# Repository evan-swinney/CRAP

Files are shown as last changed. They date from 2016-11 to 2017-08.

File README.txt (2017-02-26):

The Common Rocketry Avionics Package (CRAP) project is a rocket avionics package, designed specifically for UAH Space Hardware Club to be flown on the multistage team's rocket.  This payload will also serve as an in-house alternative to L1 Certifications and general rocketry for data collection and GPS tracking.  This payload will fire all rocket ordance and motors as well as provide data telemetry and storage.

. . . . . . . . . . . . . . . . . . . . . . . . . . . . . . . . . . . . . . . . . . . 

Designed by:
Cooper Barry - Team lead
Evan Swinney - Hardware design
James Biaglow - Hardware design and integration
Daniel Corey - Software Design
Will Watson - Software Design

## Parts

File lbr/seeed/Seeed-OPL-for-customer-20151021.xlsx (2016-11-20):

OPL list
Seeed SKU | MPN | Description | Category | Package | Manufacturer | Datasheet | Price（$）/pcs | Pieces/set | Solder points Qty | Assem.Cost/pcs（$） | Image URL | Distributor-URL
306010055 | FC-135 | SMD Crystal ABS07-32.768KHZ-7pF-20ppm-70K; | Crystal Oscillator | 2P-L3.2*W1.5mm | Xinhunjing | http://www.seeedstudio.com/wiki/images/7/78/306010055.pdf | 0.350 | 5 | 4 | 0.40 |  | http://www.seeedstudio.com/depot/OPLopen-parts-library-catalog-c-136_138/#306010055
306010005 | 49S | DIP Crystal 25MHz-20pF-20ppm;HC49US | Crystal Oscillator | HC49US | Xinhunjing | http://www.seeedstudio.com/wiki/images/5/5e/306010005.pdf | 0.150 | 10 | 2 | 0.20 |  | http://www.seeedstudio.com/depot/OPLopen-parts-library-catalog-c-136_138/#306010005
306010037 | 49S/18PF | DIP Crystal 16MHz-18pF-30ppm-50R; | Crystal Oscillator | HC49/US | Xinhunjing | http://www.seeedstudio.com/wiki/images/5/57/306010037.pdf | 0.150 | 10 | 2 | 0.20 |  | http://www.seeedstudio.com/depot/OPLopen-parts-library-catalog-c-136_138/#306010037
306010054 | X053201602002 | SMD 16MHz-8pF-20ppm-40R | Crystal Oscillator | 2P-SMD-5.0X3.2 | JINGPENGYUAN | http://www.seeedstudio.com/wiki/images/9/9f/0500290P1.pdf | 0.350 | 5 | 2 | 0.20 |  | http://www.seeedstudio.com/depot/OPLopen-parts-library-catalog-c-136_138/#0500290P1
306010047 | 5032/2P | SMD Crystal 12Mhz-20pF-20ppm-40R; | Crystal Oscillator | 2P-L5.0*W3.2mm | Xinhunjing | http://www.seeedstudio.com/wiki/images/c/c7/306010047.pdf | 0.450 | 5 | 2 | 0.20 |  | http://www.seeedstudio.com/depot/OPLopen-parts-library-catalog-c-136_138/#306010047
306010004 | 5032/4P | SMD Crystal 8MHz-20pF-20ppm; | Crystal Oscillator | 2P-L5.0*W3.2mm | Xinhunjing | http://www.seeedstudio.com/wiki/images/9/91/306010004.pdf | 0.450 | 5 | 2 | 0.20 |  | http://www.seeedstudio.com/depot/OPLopen-parts-library-catalog-c-136_138/#306010004
306010033 | 49S8M | DIP Crystal 8MHz-20pF-20ppm-60R; | Crystal Oscillator | HC49S | Xinhunjing | http://www.seeedstudio.com/wiki/images/c/ca/306010033.pdf | 0.150 | 10 | 2 | 0.20 |  | http://www.seeedstudio.com/depot/OPLopen-parts-library-catalog-c-136_138/#306010033
305030028 | 2N7002,215 | SMD MOSFET N-CH 60V-300mA Logic Level FET; | Transistor | SOT-23 | NXP | http://www.seeedstudio.com/wiki/images/c/c6/305030028.pdf | 0.050 | 30 | 3 | 0.30 |  | http://www.seeedstudio.com/depot/OPLopen-parts-library-catalog-c-136_138/#305030028
305030015 | CJ2302 | SMD MOSFET N-CH 20V 2.1A | Transistor | SOT23 | JCET | http://www.seeedstudio.com/wiki/images/e/e7/0440200P1.pdf | 0.100 | 10 | 3 | 0.30 |  | http://www.seeedstudio.com/depot/OPLopen-parts-library-catalog-c-136_138/#0440200P1
305030018 | Si2343CDS | SMD MOSFET P-CH 30V-5.9A | Transistor | SOT-23 | Vishay Siliconix |  | 0.700 | 5 | 3 | 0.30 |  | http://www.seeedstudio.com/depot/OPLopen-parts-library-catalog-c-136_138/#305030018
305030014 | CJ2305 | SMD MOSFET P-CH -8V -4.1A | Transistor | SOT-23 | JCET | http://www.seeedstudio.com/wiki/images/a/ac/0440210P1.pdf | 0.100 | 10 | 3 | 0.30 |  | http://www.seeedstudio.com/depot/OPLopen-parts-library-catalog-c-136_138/#0440210P1
305010018 | S9013 | SMD Transistors NPN 25V-500mA | Transistor | SOT-23 | JCET | http://www.seeedstudio.com/wiki/images/6/67/0400000P1.pdf | 0.040 | 50 | 3 | 0.30 |  | http://www.seeedstudio.com/depot/OPLopen-parts-library-catalog-c-136_138/#0400000P1
305020006 | S8550 | SMD Transistors PNP 25V-500mA | Transistor | SOT-23 |  | http://www.seeedstudio.com/wiki/images/e/e5/0410030P1.pdf | 0.040 | 50 | 3 | 0.30 |  | http://www.seeedstudio.com/depot/OPLopen-parts-library-catalog-c-136_138/#0410030P1
305010017 | S8050 | SMD Transistors NPN 25V-500mW; | Transistor | SOT-23 | JCET | http://www.seeedstudio.com/wiki/images/b/ba/305010017.pdf | 0.040 | 50 | 3 | 0.30 |  | http://www.seeedstudio.com/depot/OPLopen-parts-library-catalog-c-136_138/#305010017
305010022 | S9014J6 | SMD Transistor NPN 50V-100mA; | Transistor | SOT-23 | Changjiang | http://www.seeedstudio.com/wiki/images/2/2c/305010022.pdf | 0.050 | 30 | 3 | 0.30 |  | http://www.seeedstudio.com/depot/OPLopen-parts-library-catalog-c-136_138/#305010022
312010004 | KS-12065D03YA | DIP Buzzer 3V,30mA, 2700±300Hz | Audio product | 2P-7.6-D12*H6.5mm | Guangjixing | http://www.seeedstudio.com/wiki/images/c/cb/312020003.pdf | 0.500 | 5 | 2 | 0.20 |  | http://www.seeedstudio.com/depot/OPLopen-parts-library-catalog-c-136_138/#312010004
302020027 | TAJD477M006RNJ | SMD CAP Tantalum 470uF-6.3V;D | Capacitor | AVX-D | AVX |  | 0.500 | 5 | 2 | 0.20 |  | http://www.seeedstudio.com/depot/OPLopen-parts-library-catalog-c-136_138/#302020027
302030031 |  | DIP CAP Aluminum 100uF-16V | Capacitor | Radial-D5.0*H7.0mm | JWCO | http://www.seeedstudio.com/wiki/images/1/14/302030031.pdf | 0.030 | 50 | 2 | 0.20 |  | http://www.seeedstudio.com/depot/OPLopen-parts-library-catalog-c-136_138/#302030031
302020025 | TAJC107K010RNJ | SMD CAP Tantalum 100uF-10V 10% | Capacitor | AVX-C | AVX | http://www.seeedstudio.com/wiki/images/a/ae/0130170P1.pdf | 0.200 | 10 | 2 | 0.20 |  | http://www.seeedstudio.com/depot/OPLopen-parts-library-catalog-c-136_138/#0130170P1
302020022 | TAJC476K016RNJ | SMD CAP Tantalum 47uF-16V | Capacitor | AVX-C | AVX | http://www.seeedstudio.com/wiki/images/c/c7/302020022.pdf | 0.200 | 10 | 2 | 0.20 |  | http://www.seeedstudio.com/depot/OPLopen-parts-library-catalog-c-136_138/#302020022
302020020 | TAJB476K010RNJ | SMD CAP Tantalum 47uF-10V 10% | Capacitor | AVX-B | AVX | http://www.seeedstudio.com/wiki/images/f/fb/0130180P1.pdf | 0.200 | 10 | 2 | 0.20 |  | http://www.seeedstudio.com/depot/OPLopen-parts-library-catalog-c-136_138/#0130180P1
302020005 | TAJC476K006RNJ | SMD CAP Tantalum 47uF-6.3V | Capacitor | AVX-A | AVX |  | 0.150 | 20 | 2 | 0.20 |  | http://www.seeedstudio.com/depot/OPLopen-parts-library-catalog-c-136_138/#302020005
302020026 | TAJC226K025RNJ | SMD CAP Tantalum 22uF-25V 10% 2312 | Capacitor | AVX-C | AVX | http://www.seeedstudio.com/wiki/images/f/fd/0130360P1.pdf | 0.370 | 10 | 2 | 0.20 |  | http://www.seeedstudio.com/depot/OPLopen-parts-library-catalog-c-136_138/#0130360P1
302020021 | TAJB226K010RNJ | SMD CAP Tantalum 22uF-10V 10% | Capacitor | AVX-B | AVX | http://www.seeedstudio.com/wiki/images/8/82/0130240P1.pdf | 0.130 | 20 | 2 | 0.20 |  | http://www.seeedstudio.com/depot/OPLopen-parts-library-catalog-c-136_138/#0130240P1
302010171 | CC0805MKX5R5BB226 | SMD CAP Ceramic 22uF-6.3V-20%-X5R; | Capacitor | 0805 | YAGEO |  | 0.050 | 50 | 2 | 0.20 |  | http://www.seeedstudio.com/depot/OPLopen-parts-library-catalog-c-136_138/#302010171
302010181 | CC1206KKX5R8BB106 | SMD CAP Ceramic 10uF-25V-10%-X5R | Capacitor | 1206 | YAGEO |  | 0.130 | 20 | 2 | 0.20 |  | http://www.seeedstudio.com/depot/OPLopen-parts-library-catalog-c-136_138/#302010181
302010178 | CC0805KKX5R8BB106 | SMD CAP Ceramic 10uF-25V-10%-X5R | Capacitor | 0805 | YAGEO | http://www.seeedstudio.com/wiki/images/2/20/0100080P1.pdf | 0.050 | 50 | 2 | 0.20 |  | http://www.seeedstudio.com/depot/OPLopen-parts-library-catalog-c-136_138/#0100080P1
302020019 | TAJB106K016RNJ | SMD CAP Tantalum 10uF-16V 10% | Capacitor | AVX-B | AVX | http://www.seeedstudio.com/wiki/images/f/f6/0130120P1.pdf | 0.150 | 20 | 2 | 0.20 |  | http://www.seeedstudio.com/depot/OPLopen-parts-library-catalog-c-136_138/#0130120P1
302020002 | TAJA106K016RNJ | SMD CAP Tantalum 10uF-16V 10% | Capacitor | AVX-A | AVX | http://www.seeedstudio.com/wiki/images/1/1b/0130050P1.pdf | 0.130 | 20 | 2 | 0.20 |  | http://www.seeedstudio.com/depot/OPLopen-parts-library-catalog-c-136_138/#0130050P1
302020011 | TAJA106K010RNJ | SMD CAP Tantalum 10uF-10V 10% | Capacitor | AVX-A | AVX | http://www.seeedstudio.com/wiki/images/5/59/0130040P1.pdf (http://www.seeedstudio.com/wiki/images/0/0d/302010146.pdf) | 0.130 | 20 | 2 | 0.20 |  | http://www.seeedstudio.com/depot/OPLopen-parts-library-catalog-c-136_138/#0130040P1
302010243 | CC1206KKX5R9BB475 | SMD CAP Ceramic 4.7uF-50V-10%-X5R; | Capacitor | 1206 | YAGEO |  | 0.250 | 10 | 2 | 0.20 |  | http://www.seeedstudio.com/depot/OPLopen-parts-library-catalog-c-136_138/#302010243
302010146 | CC0805KKX5R8BB475 | SMD CAP Ceramic 4.7uF-25V-10%-X5R;0805 | Capacitor | C0805 | YAGEO | http://www.seeedstudio.com/wiki/images/0/0d/302010146.pdf | 0.040 | 50 | 2 | 0.20 |  | http://www.seeedstudio.com/depot/OPLopen-parts-library-catalog-c-136_138/#302010146
302010111 | CC0603KRX5R6BB475 | SMD CAP Ceramic 4.7uF-10V-10%-X5R; | Capacitor | 0603 | YAGEO |  | 0.040 | 50 | 2 | 0.20 |  | http://www.seeedstudio.com/depot/OPLopen-parts-library-catalog-c-136_138/#302010111
302010019 | CC0402MRX5R5BB475 | SMD CAP Ceramic 4.7uF-6.3V-20%-X5R | Capacitor | 0402 | YAGEO |  | 0.200 | 10 | 2 | 0.20 |  | http://www.seeedstudio.com/depot/OPLopen-parts-library-catalog-c-136_138/#302010019
302010148 | CC0805KKX7R8BB225 | SMD CAP Ceramic 2.2uF-25V-10%-X7R;0805 | Capacitor | C0805 | YAGEO | http://www.seeedstudio.com/wiki/images/a/ac/302010056.pdf | 0.050 | 50 | 2 | 0.20 |  | http://www.seeedstudio.com/depot/OPLopen-parts-library-catalog-c-136_138/#302010148
302010179 | CC0805KKX7R8BB105 | SMD CAP Ceramic 1uF-25V-10%-X7R | Capacitor | 0805 | YAGEO | http://www.seeedstudio.com/wiki/images/8/89/0100440P1.pdf (http://www.seeedstudio.com/wiki/images/a/ac/302010056.pdf) | 0.030 | 50 | 2 | 0.20 |  | http://www.seeedstudio.com/depot/OPLopen-parts-library-catalog-c-136_138/#0100440P1
302010139 | CC0603KRX7R8BB105 | SMD CAP Ceramic 1uF-25V-10%-X7R | Capacitor | 0603 | YAGEO | http://www.seeedstudio.com/wiki/images/a/af/0100340P1.pdf (http://www.seeedstudio.com/wiki/File:302010056.pdf) | 0.015 | 100 | 2 | 0.20 |  | http://www.seeedstudio.com/depot/OPLopen-parts-library-catalog-c-136_138/#0100340P1
302010040 | CC0402KRX5R6BB105 | SMD CAP Ceramic 1uF-10V-10%-X5R | Capacitor | 0402 | YAGEO |  | 0.015 | 100 | 2 | 0.20 |  | http://www.seeedstudio.com/depot/OPLopen-parts-library-catalog-c-136_138/#302010040
302010073 | CC0603KRX7R8BB224 | SMD CAP Ceramic 220nF-25V-10%-X7R;0603 | Capacitor | 0603 | YAGEO | http://www.seeedstudio.com/wiki/images/a/ac/302010056.pdf | 0.015 | 100 | 2 | 0.20 |  | http://www.seeedstudio.com/depot/OPLopen-parts-library-catalog-c-136_138/#302010073
302010165 | CC0805KRX7R9BB104 | SMD CAP Ceramic 100nF-50V-10%-X7R; | Capacitor | 0805 | YAGEO | http://www.seeedstudio.com/wiki/File:302010056.pdf (http://www.seeedstudio.com/wiki/images/a/ac/302010056.pdf) | 0.015 | 100 | 2 | 0.20 |  | http://www.seeedstudio.com/depot/OPLopen-parts-library-catalog-c-136_138/#302010165
302010138 | CC0603KRX7R9BB104 | SMD CAP Ceramic 100nF-50V-10%-X7R | Capacitor | 0603 | YAGEO | http://www.seeedstudio.com/wiki/images/3/35/0100020P1.pdf | 0.015 | 100 | 2 | 0.20 |  | http://www.seeedstudio.com/depot/OPLopen-parts-library-catalog-c-136_138/#0100020P1
302010024 | CC0402KRX7R8BB104 | SMD CAP Ceramic 100nF-25V-10%-X7R | Capacitor | 0402 | YAGEO | http://www.seeedstudio.com/wiki/images/a/ac/302010056.pdf | 0.015 | 100 | 2 | 0.20 |  | http://www.seeedstudio.com/depot/OPLopen-parts-library-catalog-c-136_138/#302010024
302010002 | CC0402KRX7R8BB473 | SMD CAP Ceramic 47nF-25V-10%-X7R; | Capacitor | 0402 | YAGEO |  | 0.010 | 100 | 2 | 0.20 |  | http://www.seeedstudio.com/depot/OPLopen-parts-library-catalog-c-136_138/#302010002
302010088 | CC0603KRX7R9BB333 | SMD CAP Ceramic 33nF-50V-10%-X7R;0603 | Capacitor | 0603 | YAGEO | http://www.seeedstudio.com/wiki/images/a/ac/302010056.pdf | 0.015 | 100 | 2 | 0.20 |  | http://www.seeedstudio.com/depot/OPLopen-parts-library-catalog-c-136_138/#302010088
302010095 | CC0603KRX7R9BB223 | SMD CAP Ceramic 22nF-50V-10%-X7R;0603 | Capacitor | C0603 | YAGEO | http://www.seeedstudio.com/wiki/images/a/ac/302010056.pdf | 0.010 | 100 | 2 | 0.20 |  | http://www.seeedstudio.com/depot/OPLopen-parts-library-catalog-c-136_138/#302010095
302010202 |  | DIP CAP Ceramic Disc 10nF-50V-Y5V | Capacitor | Radial-Disc-2.5-D4.0mm |  |  | 0.015 | 100 | 2 | 0.20 |  | http://www.seeedstudio.com/depot/OPLopen-parts-library-catalog-c-136_138/#302010202
302010140 | CC0603KRX7R9BB103 | SMD CAP Ceramic 10nF-50V-10%-X7R | Capacitor | 0603 | YAGEO | http://www.seeedstudio.com/wiki/images/e/eb/0100350P1.pdf (http://www.seeedstudio.com/wiki/images/f/f0/302010067.pdf%20302010094) | 0.010 | 100 | 2 | 0.20 |  | http://www.seeedstudio.com/depot/OPLopen-parts-library-catalog-c-136_138/#0100350P1
302010006 | CC0402KRX7R9BB103 | SMD CAP Ceramic 10nF-50V-10%-X7R | Capacitor | 0402 | YAGEO | http://www.seeedstudio.com/wiki/images/f/f0/302010067.pdf | 0.010 | 100 | 2 | 0.20 |  | http://www.seeedstudio.com/depot/OPLopen-parts-library-catalog-c-136_138/#302010006
302010144 | CC0603KRX7R9BB472 | SMD CAP Ceramic 4.7nF-50V-10%-X7R | Capacitor | 0603 | YAGEO | http://www.seeedstudio.com/wiki/images/f/fd/0130360P1.pdf | 0.010 | 100 | 2 | 0.20 |  | http://www.seeedstudio.com/depot/OPLopen-parts-library-catalog-c-136_138/#0100850P1
302010056 | CC0603KRX7R9BB222 | SMD CAP Ceramic 2.2nF-50V-10%-X7R | Capacitor | 0603 | YAGEO | http://www.seeedstudio.com/wiki/images/a/ac/302010056.pdf | 0.010 | 100 | 2 | 0.20 |  | http://www.seeedstudio.com/depot/OPLopen-parts-library-catalog-c-136_138/#302010056
302010141 | CC0603KRX7R9BB102 | SMD CAP Ceramic 1nF-50V-10%-X7R | Capacitor | 0603 | YAGEO | http://www.seeedstudio.com/wiki/images/c/cf/0100370P1.pdf | 0.010 | 100 | 2 | 0.20 |  | http://www.seeedstudio.com/depot/OPLopen-parts-library-catalog-c-136_138/#0100370P1
302010005 | CC0402KRX7R9BB102 | SMD CAP Ceramic 1nF-50V-10%-X7R; | Capacitor | 0402 | YAGEO |  | 0.050 | 50 | 2 | 0.20 |  | http://www.seeedstudio.com/depot/OPLopen-parts-library-catalog-c-136_138/#302010005
302010094 | CC0603JRNPO9BN221 | SMD CAP Ceramic 220pF-50V-5%-NPO; | Capacitor | C0603 | YAGEO | http://www.seeedstudio.com/wiki/images/f/f0/302010067.pdf 302010094 (http://www.seeedstudio.com/wiki/File:302010067.pdf) | 0.020 | 100 | 2 | 0.20 |  | http://www.seeedstudio.com/depot/OPLopen-parts-library-catalog-c-136_138/#302010094
302010013 | CC0402JRNPO9BN221 | SMD CAP Ceramic 220pF-50V-5%-NPO | Capacitor | 0402 | YAGEO | http://www.seeedstudio.com/wiki/images/f/f0/302010067.pdf | 0.030 | 50 | 2 | 0.20 |  | http://www.seeedstudio.com/depot/OPLopen-parts-library-catalog-c-136_138/#302010013
302010076 | CC0603JRNPO9BN101 | SMD CAP Ceramic 100pF-50V-5%-NPO;0603 | Capacitor | 0603 | YAGEO | http://www.seeedstudio.com/wiki/images/f/f0/302010067.pdf | 0.010 | 100 | 2 | 0.20 |  | http://www.seeedstudio.com/depot/OPLopen-parts-library-catalog-c-136_138/#302010076
302010126 | CC0603JRNPO9BN390 | SMD CAP Ceramic 39pF-50V-5%-NPO;0603 | Capacitor | C0603 | YAGEO | http://www.seeedstudio.com/wiki/images/f/f0/302010067.pdf (http://www.seeedstudio.com/wiki/images/0/03/0100230P1.pdf) | 0.010 | 100 | 2 | 0.20 |  | http://www.seeedstudio.com/depot/OPLopen-parts-library-catalog-c-136_138/#302010126
302010150 | CC0805JRNPO9BN270 | SMD CAP Ceramic 27pF-50V-5%-NPO | Capacitor | 0805 | YAGEO | http://www.seeedstudio.com/wiki/images/b/be/320020004.png | 0.030 | 50 | 2 | 0.20 |  | http://www.seeedstudio.com/depot/OPLopen-parts-library-catalog-c-136_138/#302010150
302010142 | CC0603JRNPO9BN270 | SMD CAP Ceramic 27pF-50V-5%-NPO | Capacitor | 0603 | YAGEO | http://www.seeedstudio.com/wiki/images/0/01/0100410P1.pdf (http://www.seeedstudio.com/wiki/images/b/be/320020004.png) | 0.010 | 100 | 2 | 0.20 |  | http://www.seeedstudio.com/depot/OPLopen-parts-library-catalog-c-136_138/#0100410P1
302010027 | CC0402JRNPO9BN270 | SMD CAP Ceramic 27pF-50V-5%-NPO | Capacitor | 0402 | YAGEO | http://www.seeedstudio.com/wiki/images/b/be/320020004.png | 0.010 | 100 | 2 | 0.20 |  | http://www.seeedstudio.com/depot/OPLopen-parts-library-catalog-c-136_138/#302010027
302010143 | CC0603JRNPO9BN220 | SMD CAP Ceramic 22pF-50V-5%-NPO | Capacitor | 0603 | YAGEO | http://www.seeedstudio.com/wiki/images/7/73/0100620P1.pdf | 0.010 | 100 | 2 | 0.20 |  | http://www.seeedstudio.com/depot/OPLopen-parts-library-catalog-c-136_138/#0100620P1
302010018 | CC0402JRNPO9BN220 | SMD CAP Ceramic 22pF-50V-5%-NPO | Capacitor | 0402 | YAGEO | http://www.seeedstudio.com/wiki/File:302010067.pdf (http://www.seeedstudio.com/wiki/images/b/be/320020004.png) | 0.010 | 100 | 2 | 0.20 |  | http://www.seeedstudio.com/depot/OPLopen-parts-library-catalog-c-136_138/#302010018
302010162 | CC0805JRNPO9BN180 | SMD CAP Ceramic 18pF-50V-5%-NPO | Capacitor | 0805 | YAGEO |  | 0.010 | 100 | 2 | 0.20 |  | http://www.seeedstudio.com/depot/OPLopen-parts-library-catalog-c-136_138/#302010162
302010016 | CC0402JRNPO9BN180 | SMD CAP Ceramic 18pF-50V-5%-NPO | Capacitor | 0402 | YAGEO |  | 0.010 | 100 | 2 | 0.20 |  | http://www.seeedstudio.com/depot/OPLopen-parts-library-catalog-c-136_138/#302010016
302010083 | CC0603JRNPO9BN180 | SMD CAP Ceramic 18pF-50V-5%-NPO; | Capacitor | 0603 | YAGEO | http://www.seeedstudio.com/wiki/images/7/77/320020027.png | 0.010 | 100 | 2 | 0.20 |  | http://www.seeedstudio.com/depot/OPLopen-parts-library-catalog-c-136_138/#302010083
302010082 | CC0603JRNPO9BN150 | SMD CAP Ceramic 15pF-50V-5%-NPO;0603 | Capacitor | 0603 | YAGEO | http://www.seeedstudio.com/wiki/images/f/f0/302010067.pdf (http://www.seeedstudio.com/wiki/images/e/ef/320020003.png) | 0.010 | 100 | 2 | 0.20 |  | http://www.seeedstudio.com/depot/OPLopen-parts-library-catalog-c-136_138/#302010082
302010067 | CC0603JRNPO9BN120 | SMD CAP Ceramic 12pF-50V-5%-NP0 | Capacitor | 0603 | YAGEO | http://www.seeedstudio.com/wiki/images/f/f0/302010067.pdf | 0.010 | 100 | 2 | 0.20 |  | http://www.seeedstudio.com/depot/OPLopen-parts-library-catalog-c-136_138/#302010067
302010097 | CC0603JRNPO9BN100 | SMD CAP Ceramic 10pF-50V-5%-NPO | Capacitor | 0603 | YAGEO | http://www.seeedstudio.com/wiki/images/b/be/320020004.png | 0.010 | 100 | 2 | 0.20 |  | http://www.seeedstudio.com/depot/OPLopen-parts-library-catalog-c-136_138/#302010097
302010001 | CC0402JRNPO9BN100 | SMD CAP Ceramic 10pF-50V-5%-NPO | Capacitor | 0402 | YAGEO |  | 0.010 | 100 | 2 | 0.20 |  | http://www.seeedstudio.com/depot/OPLopen-parts-library-catalog-c-136_138/#302010001
302010223 | CC0402CRNPO9BN2R2 | SMD CAP Ceramic 2.2pF-50V-0.25PF-NPO | Capacitor | 0402 | YAGEO | http://www.seeedstudio.com/wiki/images/b/be/320020004.png | 0.010 | 100 | 2 | 0.20 |  | http://www.seeedstudio.com/depot/OPLopen-parts-library-catalog-c-136_138/#302010223
302010102 | CC0603CRNPO9BN2R2 | SMD CAP Ceramic 2.2pF-50V-0.25pF-NPO | Capacitor | 0603 | YAGEO |  | 0.010 | 100 | 2 | 0.20 |  | http://www.seeedstudio.com/depot/OPLopen-parts-library-catalog-c-136_138/#302010102
302010046 | GRM1555C1H1R8BA01D | SMD CAP Ceramic 1.8pF-50V-0.1pF-NPO | Capacitor | 0402 | Murata |  | 0.010 | 100 | 2 | 0.20 |  | http://www.seeedstudio.com/depot/OPLopen-parts-library-catalog-c-136_138/#302010046
320020037 | P125-1102A0BS116A3 | DIP White Male Header VERT; | Connector | 1*2P-2.54-2.54-11.6/3.0mm | YXCON | http://www.seeedstudio.com/wiki/images/b/be/320020004.png (http://www.seeedstudio.com/wiki/images/c/cb/320020019.png) | 0.100 | 20 | 2 | 0.20 |  | http://www.seeedstudio.com/depot/OPLopen-parts-library-catalog-c-136_138/#320020037
320020015 | P125-1102A0BS116A2 | DIP Blue Male Header VERT | Connector | 1*2P-2.54-2.54-11.6/3.0mm | YXCON | http://www.seeedstudio.com/wiki/images/b/be/320020004.png | 0.100 | 20 | 2 | 0.20 |  | http://www.seeedstudio.com/depot/OPLopen-parts-library-catalog-c-136_138/#320020015
320020016 | P125-1102A0BS116A1 | DIP Black Male Header VERT | Connector | 1*2P-2.54-2.54-11.6/3.0mm | YXCON | http://www.seeedstudio.com/wiki/images/b/be/320020004.png | 0.100 | 20 | 2 | 0.20 |  | http://www.seeedstudio.com/depot/OPLopen-parts-library-catalog-c-136_138/#320020016
320020079 |  | DIP-Black-Male-Header-VERT-3P | Connector | 1X3P-2.54-2.54-11.6/3.0 | YXCON | http://www.seeedstudio.com/wiki/images/0/02/3460810P1.pdf (http://www.seeedstudio.com/wiki/images/b/be/320020004.png) | 0.100 | 20 | 3 | 0.30 |  | http://www.seeedstudio.com/depot/OPLopen-parts-library-catalog-c-136_138/#3460810P1
320020038 | P125-1103A0BS116A1 | DIP White Male Header VERT; | Connector | 1*3P-2.54-2.54-11.6/3.0mm | YXCON | http://www.seeedstudio.com/wiki/images/b/be/320020004.png | 0.120 | 20 | 3 | 0.30 |  | http://www.seeedstudio.com/depot/OPLopen-parts-library-catalog-c-136_138/#320020038
320020061 | P125-1103A0BR138A1 | DIP Black Male Header R/A; | Connector | 1*3P-2.54-2.54-6.0mm-90D-1 | YXCON |  | 0.120 | 20 | 3 | 0.30 |  | http://www.seeedstudio.com/depot/OPLopen-parts-library-catalog-c-136_138/#320020061
320020077 | P125-12A1BS116A1 | DIP Black Male Header | Connector | 2X3P-2.54-2.54-11.6/3.0 | YXCON | http://www.seeedstudio.com/wiki/images/7/72/3460180P1.pdf (http://www.seeedstudio.com/wiki/images/8/8b/320020018.png) | 0.060 | 20 | 6 | 0.60 |  | http://www.seeedstudio.com/depot/OPLopen-parts-library-catalog-c-136_138/#3460180P1
320020027 | P125-1203A0BS116A2 | DIP Yellow Male Header VERT; | Connector | 2*3P-2.54-2.54-11.6/3.0mm | YXCON | http://www.seeedstudio.com/wiki/images/7/77/320020027.png | 0.100 | 20 | 6 | 0.60 |  | http://www.seeedstudio.com/depot/OPLopen-parts-library-catalog-c-136_138/#320020027
320020003 | P125-1203A0BS116A1 | DIP Blue Male Header VERT; | Connector | 2*3P-2.54-2.54-11.6/3.0mm | YXCON | http://www.seeedstudio.com/wiki/images/e/ef/320020003.png (http://www.seeedstudio.com/wiki/images/2/25/320020010.pdf) | 0.150 | 20 | 6 | 0.60 |  | http://www.seeedstudio.com/depot/OPLopen-parts-library-catalog-c-136_138/#320020003
320020017 | P125-1104A0BS116A1 | DIP Black Male Header VERT | Connector | 1*4P-2.54-2.54-11.6/3.0mm | YXCON | http://www.seeedstudio.com/wiki/images/f/fb/320020089.png | 0.100 | 20 | 4 | 0.40 |  | http://www.seeedstudio.com/depot/OPLopen-parts-library-catalog-c-136_138/#320020017
320020005 | P125-1106A0BS116A1 | DIP Blue Male Header VERT | Connector | 1*6P-2.54-2.54-11.6/3.0mm | YXCON | http://www.seeedstudio.com/wiki/images/b/be/320020004.png | 0.100 | 20 | 6 | 0.60 |  | http://www.seeedstudio.com/depot/OPLopen-parts-library-catalog-c-136_138/#320020005
320020078 | P125-1106A1BS116A1 | DIP Black Male Header | Connector | 1X6P-2.54-2.54-11.6/3.0mm | YXCON | http://www.seeedstudio.com/wiki/images/2/2d/3460650P1.pdf | 0.100 | 20 | 6 | 0.60 |  | http://www.seeedstudio.com/depot/OPLopen-parts-library-catalog-c-136_138/#3460650P1
320020022 | P125-1106A0BS116A2 | DIP White Male Header VERT; | Connector | 1*6P-2.54-2.54-11.6/3.0mm | YXCON | http://www.seeedstudio.com/wiki/images/b/be/320020004.png (http://www.seeedstudio.com/wiki/images/0/0d/320030039.pdf) | 0.100 | 20 | 6 | 0.60 |  | http://www.seeedstudio.com/depot/OPLopen-parts-library-catalog-c-136_138/#320020022
320020024 | P125-1106B0BA2 | SMD Blue Male Header R/A; | Connector | 1*6P-2.54-2.54-9.3/6.0mm-2 | YXCON | http://www.seeedstudio.com/wiki/images/e/ef/320120007.pdf | 0.100 | 20 | 6 | 0.60 |  | http://www.seeedstudio.com/depot/OPLopen-parts-library-catalog-c-136_138/#320020024
320020031 | P125-1106B0BA1 | SMD Black Male Header R/A; | Connector | 1*6P-2.54-2.54-9.3/6.0mm-2 | YXCON | http://www.seeedstudio.com/wiki/images/d/d3/320030100.png | 0.100 | 20 | 6 | 0.60 |  | http://www.seeedstudio.com/depot/OPLopen-parts-library-catalog-c-136_138/#320020031
320020019 | P125-1106A0BR138A1 | DIP Black Short Male Header R/A; | Connector | 1X6P-2.54-2.54-6.0mm-90D-1 | YXCON | http://www.seeedstudio.com/wiki/images/c/cb/320020019.png (http://www.seeedstudio.com/wiki/images/a/a7/320030035.png) | 0.100 | 20 | 6 | 0.60 |  | http://www.seeedstudio.com/depot/OPLopen-parts-library-catalog-c-136_138/#320020019
320020070 | P125-1106A0BR138A2 | DIP Black Male Header R/A; | Connector | 1*6P-2.54-2.54-6.0mm-90D-2 | YXCON | http://www.seeedstudio.com/wiki/images/1/11/320030011.png | 0.100 | 20 | 6 | 0.60 |  | http://www.seeedstudio.com/depot/OPLopen-parts-library-catalog-c-136_138/#320020070
320020004 | P125-1108A0BS116A1 | DIP Blue Male Header VERT | Connector | 1*8P-2.54-2.54-11.6/3.0mm | YXCON | http://www.seeedstudio.com/wiki/images/b/be/320020004.png (http://www.seeedstudio.com/wiki/images/0/0d/320030039.pdf) | 0.100 | 20 | 8 | 0.80 |  | http://www.seeedstudio.com/depot/OPLopen-parts-library-catalog-c-136_138/#320020004
320020021 | P125-1108A0BS116A2 | DIP White Male Header VERT; | Connector | 1*8P-2.54-2.54-11.6/3.0mm | YXCON | http://www.seeedstudio.com/wiki/images/b/be/320020004.png | 0.100 | 20 | 8 | 0.80 |  | http://www.seeedstudio.com/depot/OPLopen-parts-library-catalog-c-136_138/#320020021
320020080 | P125-1108A1BS116A1 | DIP-Black-Male-Header-VERT-8P | Connector | 1X8P-2.54-2.54-11.6/3.0 | YXCON | http://www.seeedstudio.com/wiki/images/b/b5/3461050P1.pdf (http://www.seeedstudio.com/wiki/images/0/0d/320030039.pdf) | 0.100 | 20 | 8 | 0.80 |  | http://www.seeedstudio.com/depot/OPLopen-parts-library-catalog-c-136_138/#3461050P1
320020023 | P125-1108B0BA2 | SMD Blue Male Header R/A; | Connector | 1*8P-2.54-2.54-9.3/6.0mm-2 | YXCON | http://www.seeedstudio.com/wiki/images/0/0d/320030039.pdf | 0.120 | 20 | 8 | 0.80 |  | http://www.seeedstudio.com/depot/OPLopen-parts-library-catalog-c-136_138/#320020023
320020018 | P220-1110A0BS087A1 | DIP White Male Header VERT; | Connector | 1*10P-2.0-2.0-8.7/2.8mm | YXCON | http://www.seeedstudio.com/wiki/images/8/8b/320020018.png (http://www.seeedstudio.com/wiki/images/0/0d/320030039.pdf) | 0.200 | 10 | 10 | 1.00 |  | http://www.seeedstudio.com/depot/OPLopen-parts-library-catalog-c-136_138/#320020018
320020074 | P125-1110A0BR138A1 | DIP Black Male Header R/A; | Connector | 1*10P-2.54-2.54-6.0mm-90D-1 | YXCON | http://www.seeedstudio.com/wiki/images/e/e3/3460540P1.pdf | 0.120 | 20 | 10 | 1.00 |  | http://www.seeedstudio.com/depot/OPLopen-parts-library-catalog-c-136_138/#320020074
320020010 |  | DIP Black Male Header VERT; | Connector | 1*40P-2.54-2.54-11.6/3.0mm | YXCON | http://www.seeedstudio.com/wiki/images/2/25/320020010.pdf | 0.200 | 5 | 40 | 4.00 |  | http://www.seeedstudio.com/depot/OPLopen-parts-library-catalog-c-136_138/#320020010
320020089 | P220-1140A0BS087A1 | DIP White Male Header VERT; | Connector | 1*40P-2.0-2.0-8.7-2.8mm | YXCON | http://www.seeedstudio.com/wiki/images/f/fb/320020089.png | 0.250 | 5 | 40 | 4.00 |  | http://www.seeedstudio.com/depot/OPLopen-parts-library-catalog-c-136_138/#320020089
320020032 | P125-1140B0BA1 | SMD Black Male Header R/A; | Connector | 1*40P-2.0-2.0-4.0mm-2 | YXCON | http://www.seeedstudio.com/wiki/images/8/87/320030014.png | 0.400 | 5 | 40 | 4.00 |  | http://www.seeedstudio.com/depot/OPLopen-parts-library-catalog-c-136_138/#320020032
320020013 | P125-1140A0BR138A2 | DIP Black Short Male Header R/A; | Connector | 1*40P-2.54-2.54-6.0mm-90D-1 | YXCON |  | 0.400 | 5 | 40 | 4.00 |  | http://www.seeedstudio.com/depot/OPLopen-parts-library-catalog-c-136_138/#320020013
320030023 | F185-1102A1BSYA1 | DIP Black Female Header VERT; | Connector | 1*2P-2.54-8.5mm | YXCON | http://www.seeedstudio.com/wiki/images/0/0d/320030039.pdf | 0.150 | 10 | 2 | 0.20 |  | http://www.seeedstudio.com/depot/OPLopen-parts-library-catalog-c-136_138/#320030023
320120007 | GSL009-5.0-02P-12 | DIP Female Blue; | Connector | 2P-5.0 | SENGER | http://www.seeedstudio.com/wiki/images/e/ef/320120007.pdf (http://www.seeedstudio.com/wiki/images/0/0d/320030039.pdf) | 0.500 | 10 | 2 | 0.20 |  | http://www.seeedstudio.com/depot/OPLopen-parts-library-catalog-c-136_138/#320120007
320030100 | F185-1103A1BRYA1 | DIP Black Female Header; | Connector | 1*3P-2.54-8.5-90D | YXCON | http://www.seeedstudio.com/wiki/images/d/d3/320030100.png | 0.100 | 20 | 3 | 0.30 |  | http://www.seeedstudio.com/depot/OPLopen-parts-library-catalog-c-136_138/#320030100
320030035 | F185-1203A1BMYA1 | SMD Blue Female Header VERT | Connector | 2*3P-2.54-8.5mm | YXCON | http://www.seeedstudio.com/wiki/images/a/a7/320030035.png | 0.270 | 10 | 6 | 0.60 |  | http://www.seeedstudio.com/depot/OPLopen-parts-library-catalog-c-136_138/#320030035
320030011 | F185-1203A1BSYA1 | DIP Black Female Header VERT | Connector | 2*3P-2.54-8.5mm | YXCON | http://www.seeedstudio.com/wiki/images/1/11/320030011.png (http://www.seeedstudio.com/wiki/images/2/2d/320030013.png) | 0.200 | 10 | 6 | 0.60 |  | http://www.seeedstudio.com/depot/OPLopen-parts-library-catalog-c-136_138/#320030011
320030017 | F185-1104A1BSYA1 | DIP Black Female Header VERT | Connector | 1*4P-2.54-8.5mm | YXCON | http://www.seeedstudio.com/wiki/images/0/0d/320030039.pdf (http://www.seeedstudio.com/wiki/images/c/c9/320030076.png) | 0.150 | 10 | 4 | 0.40 |  | http://www.seeedstudio.com/depot/OPLopen-parts-library-catalog-c-136_138/#320030017
320030066 |  | DIP Long Blue Female Header | Connector | 2X3P-2.54-8.5+1.5-12.3 | YXCON | http://www.seeedstudio.com/wiki/images/0/01/3461240P1.pdf (http://www.seeedstudio.com/wiki/images/7/70/320030001.pdf) | 0.250 | 10 | 6 | 0.60 |  | http://www.seeedstudio.com/depot/OPLopen-parts-library-catalog-c-136_138/#3461240P1
320030019 | F185-1106A1BSYA3 | DIP Yellow Female Header VERT; | Connector | 1*6P-2.54-8.5mm | YXCON | http://www.seeedstudio.com/wiki/images/0/0d/320030039.pdf | 0.200 | 10 | 6 | 0.60 |  | http://www.seeedstudio.com/depot/OPLopen-parts-library-catalog-c-136_138/#320030019
320030012 | F185-1106A1BSYA2 | DIP Long Black Female Header VERT | Connector | 1*6P-2.54-8.5mm | YXCON | http://www.seeedstudio.com/wiki/images/0/0d/320030039.pdf (http://www.seeedstudio.com/wiki/images/f/f2/3460170P1.pdf) | 0.250 | 10 | 6 | 0.60 |  | http://www.seeedstudio.com/depot/OPLopen-parts-library-catalog-c-136_138/#320030012
320030004 | F185-1106A1BSYA1 | DIP Blue Female Header VERT | Connector | 1*6P-2.54-8.5mm | YXCON | http://www.seeedstudio.com/wiki/images/0/0d/320030039.pdf (http://www.seeedstudio.com/wiki/images/c/c5/320030020.png) | 0.200 | 10 | 6 | 0.60 |  | http://www.seeedstudio.com/depot/OPLopen-parts-library-catalog-c-136_138/#320030004
320030063 | F185-1106A1BSYA4 | DIP White Female Header | Connector | 1X6P-2.54-8.5 | YXCON | http://www.seeedstudio.com/wiki/images/e/e3/3460540P1.pdf | 0.200 | 10 | 6 | 0.60 |  | http://www.seeedstudio.com/depot/OPLopen-parts-library-catalog-c-136_138/#3460540P1
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

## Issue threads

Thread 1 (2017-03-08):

USB Power

cb0098, 2017-03-08:
1. Need a USB connector on the board, and there are no Micro USBs in the libraries.
2. Need to find a diode to steer the power when a battery and USB power are applied
3. Need to route the communication lines

evan-swinney, 2017-03-09:
I will see about finding a pre-existing library that has a micro in it, otherwise I'll just make one.  I think using a Schottky diode for the 5V shouldn't be an issue for the computer powering the board.  Just remember the CRAP board is the slave; it receives all power, gives none.

evan-swinney, 2017-07-21:
Upon further research, it'd be pointless to connect the USB data lines to anything on our board.

cb0098, 2017-07-21:
How will we debug then? Serial?

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

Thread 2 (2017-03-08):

H3LIS100DL data communication

cb0098, 2017-03-08:
Need to select I2C or SPI data communication for the H3LIS100DL on the HIGH_G module. Then need to wire appropriately to the micro-controller.

evan-swinney, 2017-03-09:
Can you figure out how many SPI and I2C lines we are currently using?  We might could consolidate one or two devices that aren't flight critical

evan-swinney, 2017-07-21:
Fixed in commit 2acb60c219474ad9de83404f87183629aabc7795

Closed 2017-07-21.

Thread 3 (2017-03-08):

Multiple nets

cb0098, 2017-03-08:
There are some modules where I want the same net to be called two different names due to their different functionalities yet same net. Need to remove the multiple names and move the connections outside the modules.

Modules affected:
FIRING_CIRCUIT for pins (CONT_STAT and PYRO–) and (ORD_PWR and PYRO+)
BREAKWIRE for pins BW– and BW_STAT

evan-swinney, 2017-03-09:
I'm not sure how to do this, I've always just used the same net name, but either made a note or a mental note that the other net that is connecting to something is supposed to be that way.

cb0098, 2017-04-01:
Fixed in latest push on 2017-04-01, 13:03 UTC–5. Combined the troublesome pin name into one name.

Closed 2017-04-01.

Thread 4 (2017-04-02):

Add in schematic MS5611 I2C lines

evan-swinney, 2017-04-02:

evan-swinney, 2017-07-21:
Fixed in 2acb60c219474ad9de83404f87183629aabc7795

Closed 2017-07-21.

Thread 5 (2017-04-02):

Add in schematic MPU9250 I2C lines

evan-swinney, 2017-04-02:

evan-swinney, 2017-07-21:
Fixed in 2acb60c219474ad9de83404f87183629aabc7795

Closed 2017-07-21.

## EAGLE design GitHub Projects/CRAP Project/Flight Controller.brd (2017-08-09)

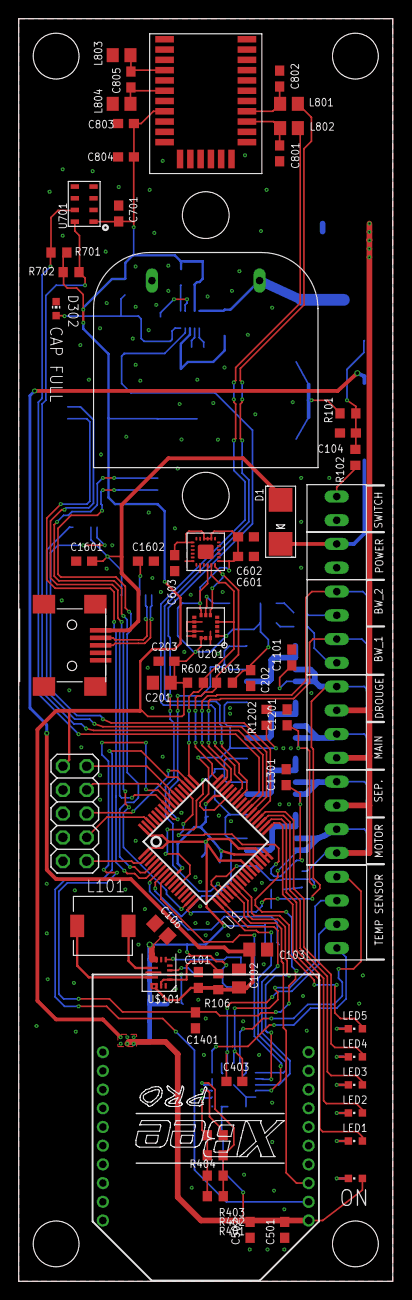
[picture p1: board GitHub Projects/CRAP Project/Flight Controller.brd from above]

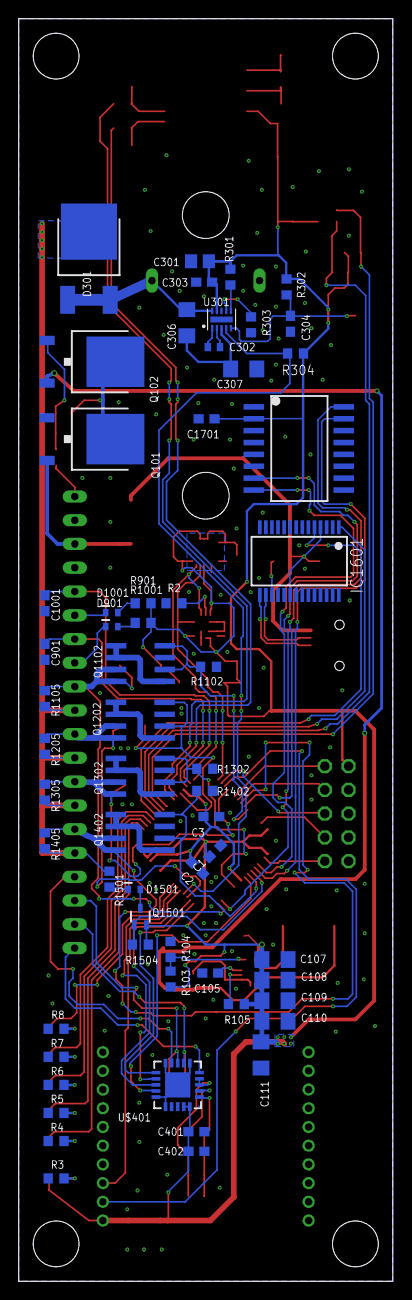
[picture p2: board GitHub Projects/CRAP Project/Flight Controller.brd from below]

Board: 2 copper layers, 40.0 x 135.0 mm, 127 parts (60 on the bottom side), 94 nets.

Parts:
C1: 4.7u; C0603
C2, C303, C502: 1u; C0603
C3, C105, C701: 100n; C0603
C101: 10u; C0603
C102, C103, C106, C201: 10u; C0805
C104: 2.2 u; C0603
C107, C108, C109, C110, C111: 22u; C1206
C202, C203, C304, C501, C601, C603, C901, C1001, C1101, C1201, C1301, C1401, C1601, C1602, C1701: 0.1u; C0603
C301: 2.2u; C0805
C302: 1u; C0402
C305: AVX_1F_5V_FOLDED
C306, C307: 100u; C1206
C401, C402: 0.1 u; C0603
C403: 100 n; C0603
C602: 10n; C0603
C801, C802, C803: 22p; C0603
C804: 2.2u; C0603
C805: 18p; C0603
CN1: USB-MINIB
D1: B160-13-F; SMADIODE
D301: RB095BM-30; TO252
D302: LTST-C193KRKT-2A; CHIP-LED0603
D901, D1001, D1501: CES521SOD523; SOD523
IC1601: FT232RL; SSOP28
J1, J101: 2POS_SCREWTERM; 2POS_0.1
J2, J3, J4, J5: 4POS_SCREWTERM; 4POS_0.1
JP1: 2X05
L101: B82462G4102M; B82462G4
L801, L802: 47n; R0805
L803, L804: 2.2u; R0805
LED1, LED2, LED3, LED4, LED5: BLUE; CHIPLED_0603
ON: RED; CHIPLED_0603
Q101, Q102: IPD042P03L3G; TO252
Q1102, Q1202, Q1302, Q1402: DMG4800LSD; SO-08
Q1501: PMF170XP; SOT323
R2, R106, R301, R304, R901, R1001: 10k; R0603
R3, R4, R5, R6, R7, R8: R0603
R101, R105: 100k; R0603
R102: 1k; R0603
R103: 470k; R0603
R104: 150k; R0603
R302, R701, R702: 2.2k; R0603
R303: 12k; R0603
R401, R402, R403: 1.2 k; R0603
R404: 10 M; R0603
R602, R603: 2.2K; R0603
R1102, R1202, R1302, R1402, R1501, R1504: 10 k; R0603
R1105, R1205, R1305, R1405: 1M; R0603
U1: G55J19; SQFP-S-10X10-64
U201: HDLIS100DL; TFLGA16L
U301: LTC3225; DFN10-2X3
U601: MPU9250; QFN-24
U701: MS5611
U1701: MT29F1G01; SOP16
U$101: TPS6307X; VQFN15_2.5X3
U$401: MAX31865; TQFN20-5X5
U$801: M10478-A3
XB501: XBEE-PRO

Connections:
+3V3: C1.1, C106.1, C107.1, C108.1, C109.1, C110.1, C111.1, C201.1, C202.1, C203.1, C301.1, C303.1, C401.1, C402.1, C501.1, C502.1, C601.1, C602.1, C603.1, C701.1, C803.2, C804.2, C1701.1, JP1.1, ON.A, Q1501.3, R103.2, R105.2, R301.2, R302.2, R304.2, R602.2, R603.2, R701.2, R702.2, R901.2, R1001.2, R1504.2, U1.1, U1.27, U1.31, U1.32, U1.64, U201.P1, U201.P8, U201.P14, U201.P15, U301.P9, U601.1, U601.8, U601.9, U601.10, U601.13, U601.22, U701.1, U701.2, U1701.2, U$101.P7, U$101.P8, U$401.19, U$401.20, U$801.8, XB501.1
+5V: C1601.2, CN1.VBUS, D1.A, IC1601.4, IC1601.20
BREAKWIRE1:N$1: D901.A, R901.1
BREAKWIRE2:N$1: D1001.A, R1001.1
BW1_STATUS: C901.1, J5.2, U1.46
BW2_STATUS: C1001.1, J5.4, U1.47
C4:N$2: D1501.A, Q1501.1
C4:N$3: D1501.C, R1501.2
DCDC_REGULATOR:N$1: Q101.3, Q102.3, R101.2
DCDC_REGULATOR:N$3: L101.P$1, U$101.P11
DCDC_REGULATOR:N$4: C104.1, Q102.1, R101.1, R102.1
DCDC_REGULATOR:N$5: L101.P$2, U$101.P9
DCDC_REGULATOR:N$6: J101.2, R102.2
DCDC_REGULATOR:N$7: C105.1, U$101.P3
DCDC_REGULATOR:N$9: R105.1, U$101.P2
DCDC_REGULATOR:N$10: R103.1, R104.2, U$101.P5
DCDC_REGULATOR:N$11: R106.1, U$101.P1, U$101.P14
DCDC_REGULATOR:VIN: C101.1, C102.1, C103.1, Q102.2, R106.2, U$101.P12, U$101.P13
FC1-: C1401.1, J3.2, Q1402.7, Q1402.8, R1405.1, U1.56
FC1_FIRE: Q1402.2, Q1402.4, R1402.2, U1.7
FC2-: C1301.1, J3.4, Q1302.7, Q1302.8, R1305.1, U1.52
FC2_FIRE: Q1302.2, Q1302.4, R1302.2, U1.11
FC3-: C1201.1, J4.2, Q1202.7, Q1202.8, R1205.1, U1.19
FC3_FIRE: Q1202.2, Q1202.4, R1202.2, U1.44
FC4-: C1101.1, J4.4, Q1102.7, Q1102.8, R1105.1, U1.16
FC4_FIRE: Q1102.2, Q1102.4, R1102.2, U1.58
FC_!CONT_EN: Q1501.2, R1504.1, U1.6
FIRING_CIRCUIT1:N$1: Q1402.1, Q1402.5, Q1402.6
FIRING_CIRCUIT2:N$1: Q1302.1, Q1302.5, Q1302.6
FIRING_CIRCUIT3:N$1: Q1202.1, Q1202.5, Q1202.6
FIRING_CIRCUIT4:N$1: Q1102.1, Q1102.5, Q1102.6
FT1:N$5: C1602.1, IC1601.17
GND: C1.2, C2.1, C3.1, C101.2, C102.2, C103.2, C104.2, C105.2, C106.2, C107.2, C108.2, C109.2, C110.2, C111.2, C201.2, C202.2, C203.2, C301.2, C303.2, C304.2, C305.2, C307.2, C401.2, C402.2, C501.2, C502.2, C601.2, C602.2, C603.2, C701.2, C801.2, C802.2, C803.1, C804.1, C901.2, C1001.2, C1101.2, C1201.2, C1301.2, C1401.2, C1601.1, C1602.2, C1701.2, CN1.GND, D302.C, IC1601.7, IC1601.18, IC1601.21, IC1601.25, J1.2, J101.1, JP1.3, JP1.5, JP1.9, L803.1, L804.1, Q101.1, Q1102.3, Q1202.3, Q1302.3, Q1402.3, R2.1, R3.1, R4.1, R5.1, R6.1, R7.1, R8.1, R104.1, R303.1, R1102.1, R1202.1, R1302.1, R1402.1, U1.13, U1.29, U1.53, U201.P5, U201.P10, U201.P12, U201.P13, U201.P16, U301.P8, U301.P11, U601.18, U601.20, U701.3, U701.4, U701.5, U1701.10, U$101.P4, U$101.P6, U$101.P10, U$101.P15, U$401.6, U$401.10, U$401.15, U$401.16, U$401.EXP, U$801.1, U$801.2, U$801.3, U$801.5, U$801.7, U$801.9, U$801.15, U$801.16, U$801.17, U$801.19, U$801.22, U$801.23, U$801.24, U$801.25, U$801.27, U$801.28, XB501.10
GPS1:N$1: C805.1, L803.2, U$801.4
GPS1:N$2: C802.1, L801.1, U$801.21
GPS1:N$3: C801.1, L802.1, U$801.20
GPS1:N$4: C805.2, L804.2, U$801.6
GPS_RX: L801.2, U1.42
GPS_TX: L802.2, U1.43
IMU_SCL: R602.1, U1.49, U201.P4, U601.23
IMU_SDA: R603.1, U1.48, U201.P6, U601.24
MEM_!CS: U1.15, U1701.7
MEM_MISO: U1.4, U1701.8
MEM_MOSI: U1.5, U1701.15
MEM_SCK: U1.57, U1701.16
MS5611_SCL: R702.1, U1.39, U701.8
MS5611_SDA: R701.1, U1.40, U701.7
unnamed: JP1.2, U1.54
unnamed: JP1.4, U1.55
unnamed: JP1.6, U1.50
unnamed: JP1.8, U1.62
unnamed: JP1.10, U1.2
unnamed: J2.1, U$401.5
unnamed: C403.1, J2.2, U$401.7
unnamed: C403.2, J2.3, U$401.8
unnamed: J2.4, U$401.9
unnamed: D1001.C, J5.3
unnamed: D901.C, J5.1
unnamed: R2.2, U201.P7
unnamed: LED1.C, R4.2
unnamed: LED2.C, R5.2
unnamed: LED3.C, R6.2
unnamed: LED4.C, R7.2
unnamed: LED5.C, R8.2
unnamed: ON.C, R3.2
ORD+: D301.3, J3.1, J3.3, J4.1, J4.3, R1105.2, R1205.2, R1305.2, R1405.2, R1501.1
ORDNANCE_POWER:N$1: C302.1, U301.P1
ORDNANCE_POWER:N$2: C302.2, U301.P2
ORDNANCE_POWER:N$3: C305.1, C306.1, D301.1, D301.2, U301.P10
ORDNANCE_POWER:N$4: C304.1, D302.A, R302.1, U301.P5
ORDNANCE_POWER:N$5: R301.1, U301.P6
ORDNANCE_POWER:N$6: R303.2, U301.P7
ORDNANCE_POWER:N$7: C306.2, C307.1, U301.P3
ORD_!SHDN: R304.1, U1.20, U301.P4
RTD:N$1: R401.2, R402.2, R403.2, R404.2, U$401.1
RTD:N$4: R401.1, R402.1, R403.1, U$401.3, U$401.4
RTD:N$5: R404.1, U$401.2
RTD_!CS: U1.18, U$401.13
RTD_MISO: U1.8, U$401.14
RTD_MOSI: U1.17, U$401.11
RTD_SCK: U1.22, U$401.12
UC_LED1: LED1.A, U1.33
UC_LED2: LED2.A, U1.34
UC_LED3: LED3.A, U1.35
UC_LED4: LED4.A, U1.36
UC_LED5: LED5.A, U1.23
USB_N: CN1.D-, IC1601.16
USB_P: CN1.D+, IC1601.15
USB_RX: IC1601.5, U1.37
USB_TX: IC1601.1, U1.38
VCC_IN: D1.C, J1.1, Q101.2
VDDOUT: C2.2, C3.2, U1.9, U1.30, U1.45
XBEE_RX: U1.21, XB501.3
XBEE_TX: U1.51, XB501.2

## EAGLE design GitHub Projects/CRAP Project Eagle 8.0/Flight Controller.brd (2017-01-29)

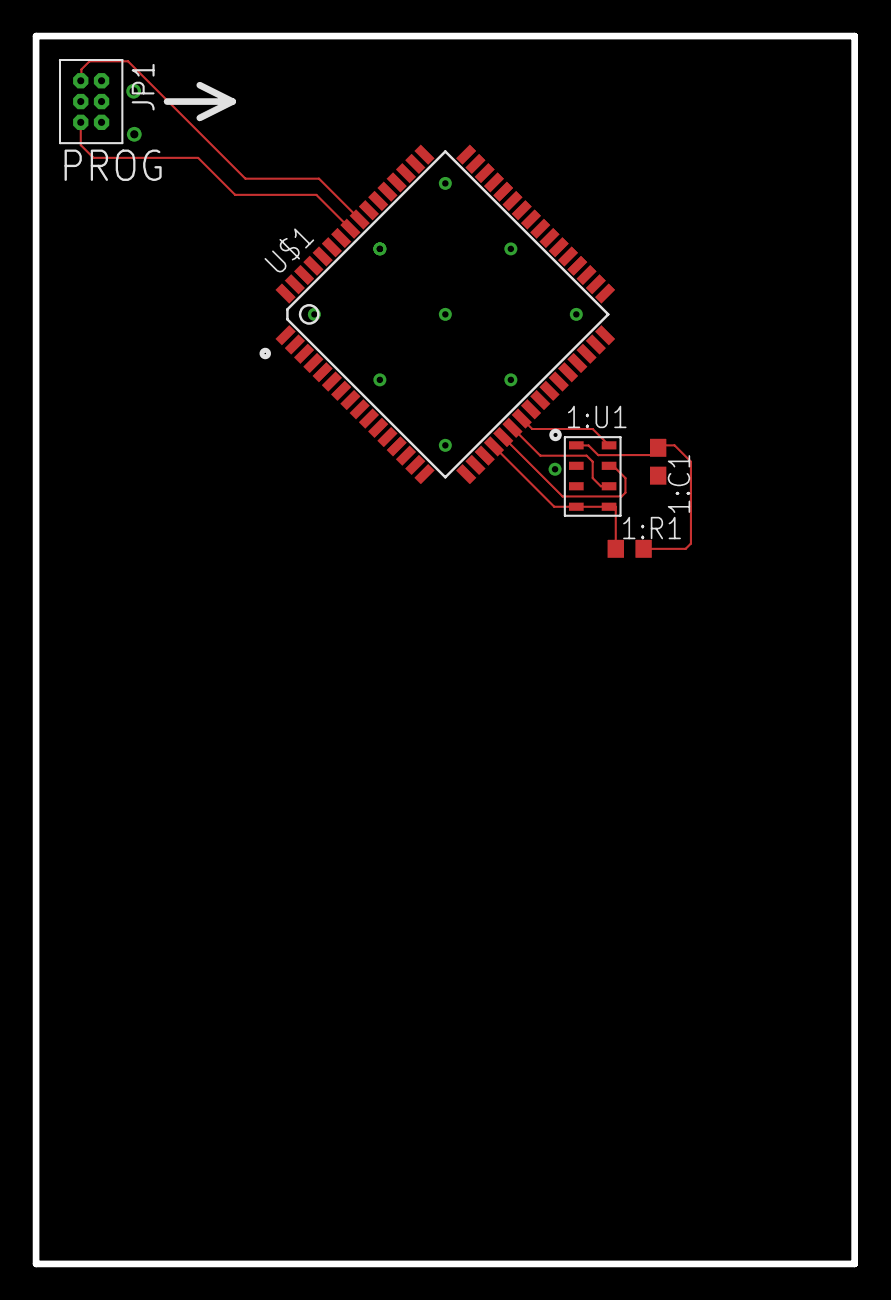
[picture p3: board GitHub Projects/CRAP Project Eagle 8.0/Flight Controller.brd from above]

Board: 2 copper layers, 50.0 x 75.0 mm, 5 parts (0 on the bottom side), 8 nets.

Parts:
1:C1: 100n; C0603
1:R1: 10k; R0603
1:U1: MS5611
JP1: 2X03
U$1: XMEGA64A3U; TQFP64

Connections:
+3V3: 1:C1.1, 1:R1.2, 1:U1.1, JP1.5, U$1.15, U$1.25, U$1.35, U$1.45, U$1.53, U$1.61
GND: 1:C1.2, 1:U1.2, 1:U1.3, JP1.1, U$1.14, U$1.24, U$1.34, U$1.44, U$1.52, U$1.60
MS5611_CS: 1:R1.1, 1:U1.4, 1:U1.5, U$1.20
MS5611_MISO: 1:U1.6, U$1.22
MS5611_MOSI: 1:U1.7, U$1.21
MS5611_SCLK: 1:U1.8, U$1.23
X_PDI_DATA: JP1.6, U$1.56
X_RESET_PDI_CLK: JP1.2, U$1.57

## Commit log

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2017-01-22 Added MS library, created schematic for the MS5611 and xMega64A3U, and routed traces for the pressure sensor and PDI interface
    Things left to do:
    1. Create MPU9250
    2. Route MPU9250
    3. Create all parts for the power system
    4. Route all parts of the power system
    5. Create all parts for the ordance system
    6. Route all parts for the ordance system
    7. Create GPS, flash, and Hi-G accelerometer
    8. Route GPS, flash, and Hi-G accelerometer
    Outstanding Issues:
    1. None at the moment
    [Flight Controller.brd, Flight Controller.sch]
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2017-01-29 Added V8.0 folder and MPU9250 part and lib
    Added the MPU block diagram to the schematic list. Also defined an
    Invensense library, which houses the MPU9250 along with a QFN-24 3x3x1mm
    package.
    [Battery Board.sch, Flight Controller.brd, Flight Controller.sch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]
2017-02-05 Added TPS63070
    Added DCDC-Converter module on Flight Computer, and the TPS6307x device
    under the Texas library
    [Flight Controller.brd, Flight Controller.sch]
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2017-02-09 Started ordnance module. Minor changes to power module
    Nothing new to power module—just modified the aesthetics. Added he
    ordnance module but mainly just the LTC3225 super-cap charging chip.
    [Flight Controller.brd, Flight Controller.sch]
2017-02-10 Created sandbox.sch
    I am using the sandbox schematic to make figures for reports. It is not
    part of the final PCB.
    [sandbox.sch]
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2017-02-23 Changed Module Offsets
    Changed module offsets to different values so that the giant names would
    go away. I feel that in future versions this feature will be more
    refined, since in V7.7 was the very first version it appeared in. The
    manual inside of the Eagle install in C:/ thankfully is updated with the
    new features and explains some of the new ways to do things better than
    anywhere I can find online. Seems that nobody online has these issues,
    or I suppose that they just automatically think to read the 1000 page
    document every update.
    [Flight Controller.brd, Flight Controller.sch]
2017-02-24 Added Screw Terminals and Schematic Frames
    Added screw in terminals of the 2, 4, and 8 widths. They are at a
    2.54mm pitch (0.1').
    Also added in schematic frames to make our things look much fancier.
    [Flight Controller.brd, Flight Controller.sch]
2017-02-25 RTD module nearly done
    1. RTD module is nearly done. Just need to figure out the connections in
    and out of modules, especially for the serial data lines and power.
    2. Touched up power and ordnance modules to include the correct ground
    symbols.
    Note: All this was done with the Eagle 7.x version files
    [Flight Controller.brd, Flight Controller.sch]
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2017-02-26 Removed the other files that aren't needed anymore
    Didn't need those files since we can do all the work in the Flight
    Controller sheet with the submodules and whatnot.
    [Battery Board.sch, Flight Controller.dxf, Ordnance Board.sch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]
2017-02-26 Added SAMG55 and AVR and SAM JTAG headers
    Created AVR JTAG headers for possible future use and also created SAM
    JTAG headers for immediate use.
    Added G55 into the root sheet and added recommended decoupling
    capacitors to VDDIO, VDDOUT, and VDDCORE.
    [Flight Controller.sch]
2017-02-26 Fixed the board consistency by making a new board
    Do not modify the schematic unless the schematic and board are
    consistant. The easiest way to do this is to just have the board open
    when you open the schematic. This is why it asks if you want to open
    both when you first open the program.
    Also added a fancy logo to the Atmel chip's footprint, also found an
    existing part for the Xbee900 Pro, so I added that into the schematic
    and made a module for it.
    Also added in modules for the memory and GPS. That will be what I work
    on next.
    Outstanding things: I think the power module is a little funky with the
    ports you have on there, Cooper. Are the two return lines not a common
    ground? Why se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
    [Flight Controller.brd, Flight Controller.sch]
2017-02-27 Module updates
    1. Fixed or added ports to the following modules: DC-DC Converter, RTD,
    Ordnance, and Firing Chains
    2. Fixed power pins within those modules
    3. Minor updates to the DC-DC Converter regarding the connections to the
    TPS63070
    4. Moved the RTD's screw terminal block to the top level sheet
    [Flight Controller.brd, Flight Controller.sch]
2017-02-28 Modules, aesthetics, library fixes
    1. Renamed Ordnance to Ordnance Power. Moved Firing chains from inside
    this module to the top level schematic.
    2. Added Breakwire module with pins. Nothing done inside the module
    3. Added IMU module with pins. Nothing done inside the module
    4. Increased soldermask expansion on TPS63070 per datasheet inside the
    Texas.lbr
    5. Fixed the header pin names, pin connections, reference designators,
    and added a frame on the schematic
    6. Got smaller diode array on Ordnance Power board per Evan's request
    7. Moved Firing Circuits to top level schematic. Previously on Ordnance
    Board
    8. Grouped like items on the top level schematic and added a frame for
    aesthetics and eas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
    [Flight Controller.brd, Flight Controller.sch]
2017-02-28 Fixed library again
    Fixed CRAP Parts library again by adding reference designator to
    silkscreen
    [Flight Controller.sch]
2017-02-28 Added frames and MPU-9250 into IMU module
    Also remade the board again because it broke.
    [Flight Controller.brd, Flight Controller.sch]
2017-02-28 Added Micron 1Gbit memory module
    1. Changed all the text to the info layer
    2. Added the Micron 1Gbit memory module
    3. Routed power and ground to it
    [Flight Controller.brd, Flight Controller.sch]
2017-03-01 Added super cap part, did prelim board layout
    1. Made a super capacitor part with a upright and folded variant.
    2. Talked with Davis about the dimensions of the board and came to the
    conclusion that 100mm tall will be alright. Also speculated that 100mm
    tall board would work with most club rockets, and confirmed with both
    supersonic teams that 100mm tall would be able to fit.
    3. Changed some of the modules in the upper level sheet to fit back on
    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
    [Flight Controller.brd, Flight Controller.sch]
2017-03-01 Changed silkscreen
    1. Changed the silkscreen from numbers with + and - to what they were
    going to be without + and -, because polarization doesn't matter when
    dealing with a resistive component.
    2. Also added the silkscreen names for the switch, temperature sensor,
    and power input.
    [Flight Controller.brd]
2017-03-04 IMU, Breakwire, Firing Chain module updates
    1. Added CES521 diode to diode.lbr
    2. Added CES521 to breakwire and pyro firing chain modules
    3. Basic wiring of IMU module
    Issues needing to be resolved with Evan
    1. Address of IMU. There is a dangling resistor ready for this on the
    top level schematic.
    2. What does FSYNC need to be wired to inside the IMU module?
    3. The breakwire and firing chain modules have two pins that I want
    connected internally but named separately. See comments inside these
    modules for more information.
    4. What value of resistors to use for the IMU I2C lines. Currently 2.2k
    [Flight Controller.brd, Flight Controller.sch]
2017-03-07 Added H3LIS100DL
    Added the H3LIS100DL to the ST-microelectronics library along with a
    3x3mm TFLGA-16 package. This device is in the HIGH_G module under
    Sensors. Things for Evan to consider on this push:
    1. Frame needed for the HIGH_G module schematic
    2. Data communication for H3LIS100DL: SPI or I2C?
    2a. If I2C, which address? Currently a resistor on the top level
    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
    [Flight Controller.brd, Flight Controller.sch]
2017-03-08 Ordnance power updates
    1. Fixed PGOOD LED on Ordnance Power module
    2. Wired output capacitors on Ordnance Power. This is a single super-cap
    configuration where two 100uF caps in series are needed fro the
    balancing circuitry.
    3. Added a frame to the HIGH_G module
    Another issue discovered:
    1. Need USB connection. There are no micro USBs in the library (unless
    I'm blind?)
    [Flight Controller.brd, Flight Controller.sch]
2017-04-01 Ordnance & Breakwire modules fixes
    1. In the Ordnance module: combined the PYRO+ and PWR to the same pin
    and called PWR/PYRO+. This is the ordnance power from the super caps.
    2. In the Ordnance module: combined CONT_STAT and PYRO– to the same pin
    and called CONT_STAT/PYRO–. Outside the modules on the top level
    schematic, I added long wires from this pin going to the left of each
    module. This is also the digital line for sensing continuity status of
    the ordnance lines.
    3. In the Breakwire module, combined BW_STAT and BW– to the same pin and
    called BW_STAT/BW–. Outside the module on the top level schematic, I
    made long lines from this pin to the right of each module. This is the
    digita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
    [Flight Controller.brd, Flight Controller.sch]
2017-04-07 Major changes
    1. Cleaned up master level sheet
    2. Changed MS5611 from SPI to I2C
    3. Routed a lot
    4. Changed MPU9250 power structure on top level (was broken)
    5. Added serial communication lines to microcontroller
    [Flight Controller.brd, Flight Controller.sch]
2017-04-07 Routed more, added GPS
    1. Added Antenova library
    2. Added our GPS to the Antenova library
    3. Placed GPS, which caused our power system to move, also increased
    board height by 5mm due to expected space constraints
    4. Moved our power system close to the Xbee
    5. Placed a MOSFET for the separation circuit
    [Flight Controller.brd, Flight Controller.sch]
2017-04-11 Routing, schematic changes
    1. Changed some schematic errors on the firing chains
    2. Routed more GPS, changed inductor on power supply, routed Xbee
    [Flight Controller.brd, Flight Controller.sch]
2017-04-11 More routing changes
    1. Changed the power circuit 180 degrees to better fit the inductor
    2. Routed a lot of the ordance circuits and placed all MOSFETS
    3. Routed lots of power
    4. Oh god it's so crowded
    [Flight Controller.brd, Flight Controller.sch]
2017-04-12 More routing
    1. Routed parts of the ordance
    2. Routed parts of the RTD
    3. Routed Parts of the breakwire
    4. Swapped RTD and breakwire headers to allow for actual routing because
    it was too cramped to fit the RTD's sensor chip in the area that the
    header was in
    [Flight Controller.brd, Flight Controller.sch]
2017-06-19 Routed some of the RTD sensor
    Moved the RTD chip under the Xbee to have more room for capacitors and
    resistors later on
    [Flight Controller.brd]
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2017-06-27 Minor Changes to some routing
    Having problems with using the alternate grid. Routing engine will not
    allow me to route on the alternate grid, which has stopped progress for
    the time being.
    [Flight Controller.brd, Flight Controller.sch]
2017-07-20 Major revisions
    1. Made board 30mm taller to allow for more space in cramped enviroment.
    Deemed absolutely critical.
    2. Majorly changed the power turn-on and turn-off MOSFETs design and
    location to clear up room in the mid-board area
    3. Moved the super capacitor nearer to the top of the extended section,
    and also made it have a verticle orientation; should allow for better
    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
    [Flight Controller.brd, Flight Controller.sch]
2017-07-21 Routing of high-g IMU, regular IMU, firing circuits
    1. Chose communication lines for all sensors and memory to the uC
    2. Routed 100% the MPU9250
    3. Routed 100% the high-g accelerometer
    4. Routed 100% the breakwire circuits
    5. Routed 75% of the firing circuits
    [Flight Controller.brd, Flight Controller.sch]
2017-07-22 More routing and schematic changes
    1. Finished 100% the schematic of all misc. connections that were going
    to things, such as all comms, all LED indication pins, and all
    enable/disable pins
    2. Added FTDI FT232R for serial to USB connectivity
    3. Routed the power line for the firing circuit from supercap
    4. Routed LED indication
    [Flight Controller.brd, Flight Controller.sch]
2017-07-31 Major routing done
    1. Routed a bunch of stuff, so much stuff that I don't know what to put
    here.
    2. Added USB Mini connector and diode routed power to protect FTDI chip
    3. Added FTDI chip for USB to UART so we can dump data to USB
    4. Added holes forward and rear of the super cap so that we can screw
    things in to hold the super cap in place
    5. Extended the height of the board by 5mm to accmodate the hole
    6. Oh god why didn't we suffer through 0402's
    [Flight Controller.brd, Flight Controller.sch]
2017-07-31 Routed GPS UART 100%
    1. Routed the GPS UART lines to the GPS and from the microcontroller.
    [Flight Controller.brd]
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2017-08-09 Finished routing CRAP [MAJOR]
    1. Finished routing everything but some ground plane issues
    2. Moved MS5611 to another location on the board because of space
    constraints that was making the groudplane too segmented to work
    properly.
    3. Finished routing the RTD 100%
    [Flight Controller.brd]
